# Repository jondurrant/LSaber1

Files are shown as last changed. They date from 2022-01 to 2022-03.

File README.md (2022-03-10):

# LSaber1
IOT Saber Wall Light based on Raspberry PI Pico, ESP-01S and WS2812 LEDs.

PIR and Switch activated wall light. Works as a group able to turn each other on and off via MQTT hub topics. 

# Hardware
+ Raspberry Pico
+ ESP-01S (1Mb) running ESP-AT 2.1
+ WS2812 144 LED strip
+ AM312 PIC
+ RGB CC LED
+ Resistors and Caps as in Schema
+ 5Amp 5Volt power supply
+ 5 Amp Fuse and 100C Thermal Fuse
+ M2 inserts for scew fixing of PCB to case and pommel onto case

## Schema 
A circuit diagram is available in KICAD format. Included in PCB folder.

Warning: The LEDs will draw 4Amps of current. You should assure yourself that the circuit and wiring can safely deliver that current. 

## ESP-01S
I got very cheap pack of ESP-01S but they came with 1Mb flash. Latest version of ESP-AT, version 2.2, requires 2MB. 

Fortunatly Jandrassy has built a working 2.1 firmware for 1MB. This is on github at: https://github.com/jandrassy/WiFiEspAT

To reliably upload the firmware to ESP-01S requires the RST IO0 to get pulled to zero and the released. Some further inform on how to do this at: https://blog.tiga.tech/flashing-esphome-firmware-to-esp-01s/

I used the RPI 4 to upload the firmware and the esptool.py. I had to drop frequency to 40m and change upload mode to dout in the download.config file. Then use the command
esptool.py --port /dev/ttyS0 write_flash @download.config

## Case
Case is 3D printed in PLA. I've modelled the case and wall mounts for the case in OpenSCAD. The model and SLA files available in the 3dmodels folder.

## Blade
Blade is a 20mm x 3mm x 1000mm OPAL Acrylic Tube. You can find these on ebay, though I found ebay quite expensive. Bought mine from [The Clear Plastic Shop](https://clearplastictube.co.uk/opal-acrylic-tube) in the UK. 

# Software

## C++ - For Raspberry PICO
+ [lwesp](https://github.com/MaJerle/lwesp): library for talking to ESP-AT over serial
+ + [forkedlwesp](https://github.com/jondurrant/lwespFork) Forked to allow MQTT over SSL. 
+ [FreeRTOS-Kernel](https://github.com/FreeRTOS/FreeRTOS-Kernel): dependency for lwesp
+ [json-maker](https://github.com/rafagafe/json-maker)
+ [tiny-json](https://github.com/rafagafe/tiny-json)
+ [RtosComponents](https://github.com/jondurrant/RtosComponents) - my library for watchdog and RGB PWM control
+ [twinThingPicoESP](https://github.com/jondurrant/twinThingPicoESP) - IOT Library
+ [PicoLED](https://github.com/ForsakenNGS/PicoLED) - Manage the WS2812 LEDs

## Python -  Management Software
+ [TwinThingPyMQTT](https://github.com/jondurrant/TwinThingPyMQTT) - Python version of IOT Library, including TwinMgr which is how the management software talks to all the devices.
+ Python3
+ dotmap
+ numpy
+ paho-mqtt
+ pandas
+ PyMySQL
+ pyOpenSSL
+ SQLAlchemy
+ [twinThing](https://github.com/jondurrant/twinThing) 
+ mysql Db
+ [emqx](https://www.emqx.io/) using Mysql authentication 
+ [Joern Weissenborn LCARS](http://joernweissenborn.github.io/lcars/) - LCARS Look and feel

## Python Test Code
Some test code to interact with the api are included in py/test folder. They expect some environment variables to point to the MQTT hub and credentials.
+ MQTT_USER - Username and Client Id to connect to MQTT
+ MQTT_PASSWD - Password to authenticate against MQTT
+ MQTT_HOST - Hostname of MQTT server
+ MQTT_PORT - Port that MQTT is listen on, normally 1883

# Build and Deploy

##Clone project
'''
git clone --recurse-submodules https://github.com/jondurrant/LSaber1
'''
main.cpp include "Credentials.env" for the Wifi AP name and passwd, MQTT Host, Port, Username and password. I've not included this file in the repo. Please create one looking something like this:

``` C++
#define SID "SID"
#define PASSWD "PWD"

#define MQTTHOST "IP"
#define MQTTPORT 1883
#define MQTTUSER "jon"
#define MQTTPASSWD "PWD"
```

## To build C++:
``` bash
mkdir build
cd build
cmake ..
make
make install (only work if you used my config setup in the Pico Intro course as does SWD upload of code direct from make).
```

For more on how I use a Raspberry PI to build, deploy code  and debug the Pico see my course on [Udemy](https://www.udemy.com/course/introduction-to-c-development-environment-for-raspberry-pico/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)

## Python Management Deployment
I have included a Docker file to build an image for the management software. It manipulates the Python path to include the right libraries, along with loading some from requirements.txt.

## EMQX
Setup EMQX using mysql authentication and acl. The [TwinThingPyMQTT](https://github.com/jondurrant/TwinThingPyMQTT) repo include the DDL to create the required tables.

Lights authenticate using the MAC address of the device for Client Id, Username and Password. They will require permissions within EMQX to access:
```
[
	{
	  "topic": "GRP/ALL/TPC/#",
	  "action": "sub",
	  "access": "allow"
	},
	{
	  "topic": "TNG/$CLIENTID/#",
	  "action": "pubsub",
	  "access": "allow"
	},
	{
	  "topic": "GRP/saber/TPC/#",
	  "action": "pubsub",
	  "access": "allow"
	}
]
```
The Management software will need access to:
```
[
	{
	  "topic": "GRP/ALL/TPC/#",
	  "action": "sub",
	  "access": "allow"
	},
	{
	  "topic": "TNG/$CLIENTID/#",
	  "action": "pubsub",
	  "access": "allow"
	},
	{
	  "topic": "GRP/saber/TPC/#",
	  "action": "pubsub",
	  "access": "allow"
	},
	{
	  "topic": "GRP/saber/TWIN/RES",
	  "action": "sub",
	  "access": "allow"
	},
	{
	  "topic": "GRP/saber/TWIN/GET",
	  "action": "pub",
	  "access": "allow"
	},
	{
	  "topic": "GRP/saber/TWIN/SET",
	  "action": "pub",
	  "access": "allow"
	}
]
```

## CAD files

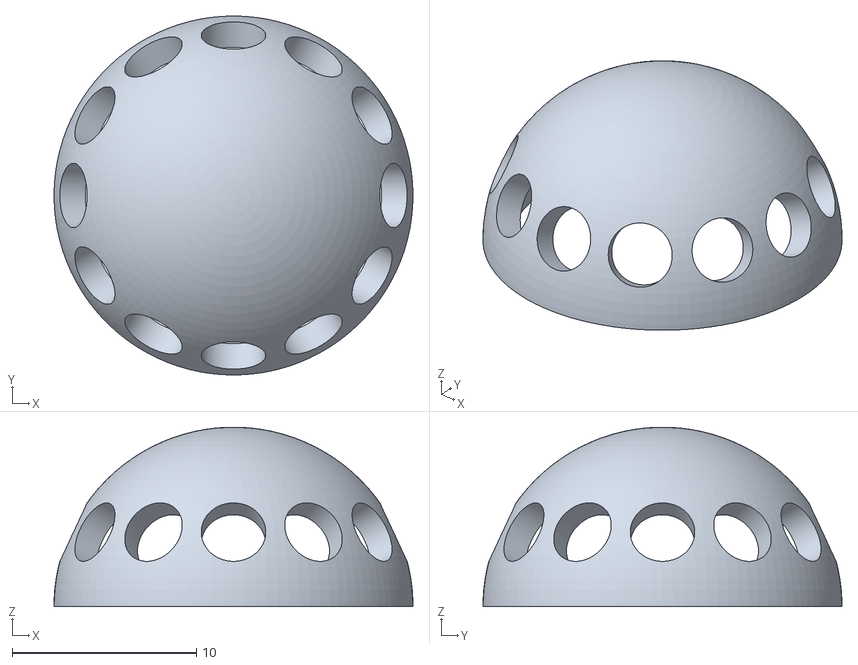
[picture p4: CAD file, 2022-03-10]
3dmodels/stl/cap.stl
19.5 x 19.5 x 9.75

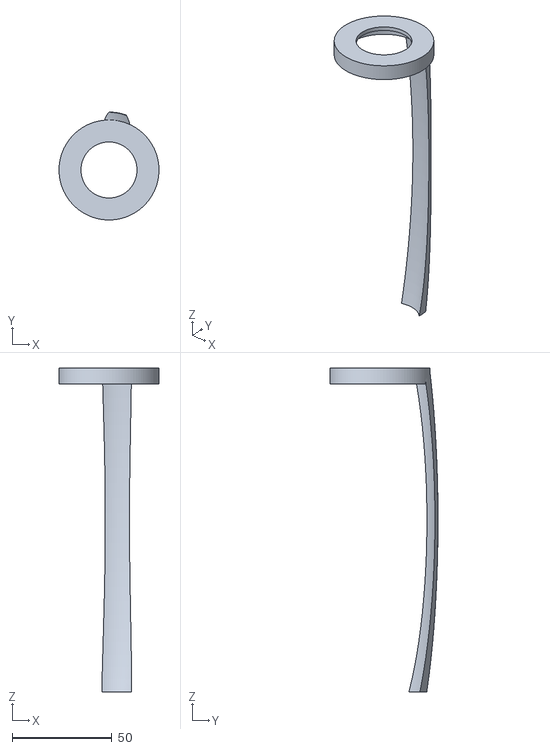
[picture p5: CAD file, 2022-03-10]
3dmodels/stl/guard.stl
50.0 x 54.0 x 162.0

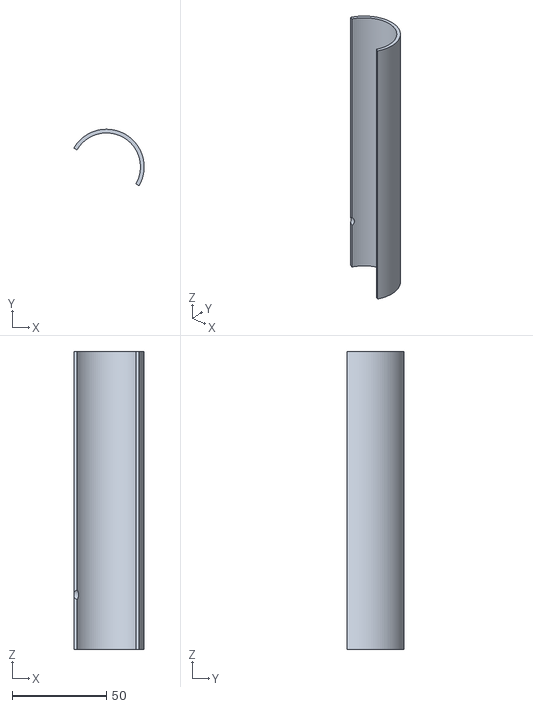
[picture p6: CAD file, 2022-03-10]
3dmodels/stl/gripRear.stl
37.3 x 30.0 x 158.0

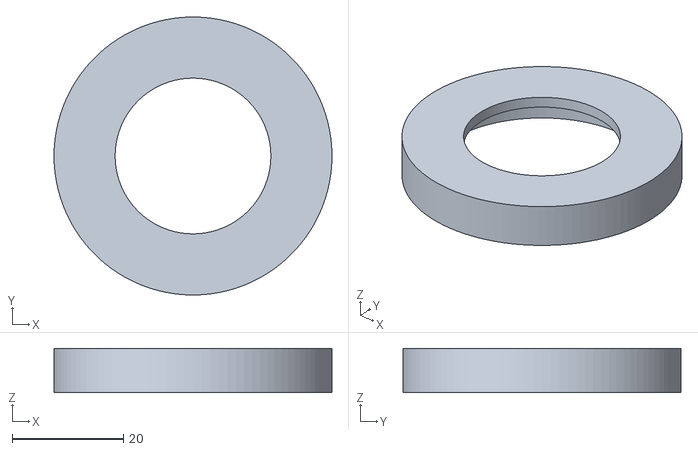
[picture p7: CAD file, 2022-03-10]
3dmodels/stl/guardShort.stl
50.0 x 50.0 x 8.00

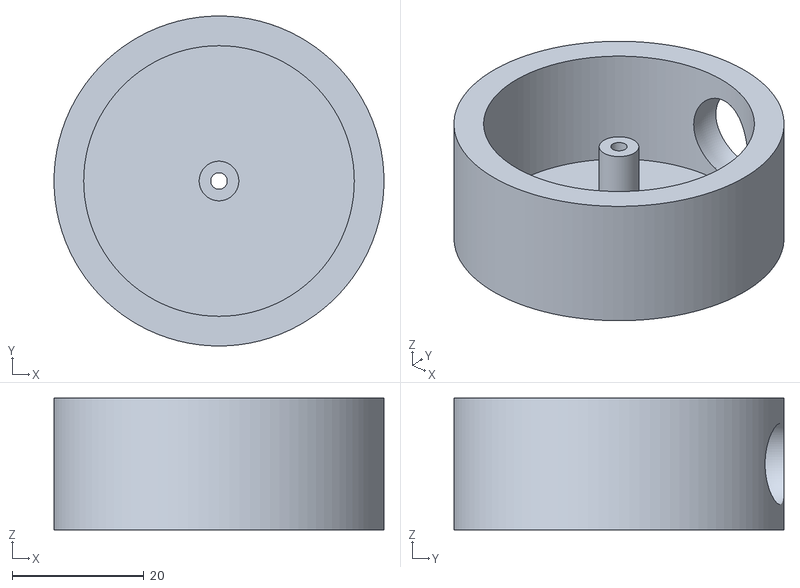
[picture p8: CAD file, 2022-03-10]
3dmodels/stl/pummel.stl
50.0 x 50.0 x 20.0

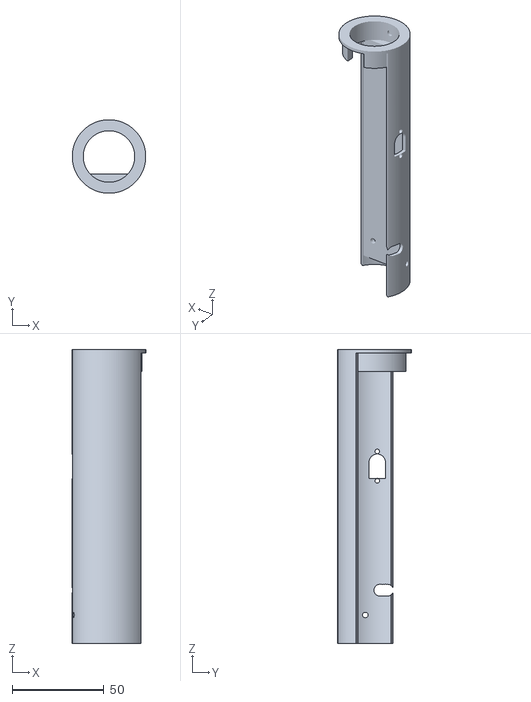
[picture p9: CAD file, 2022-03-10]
3dmodels/stl/gripBack.stl
40.0 x 40.0 x 160.0

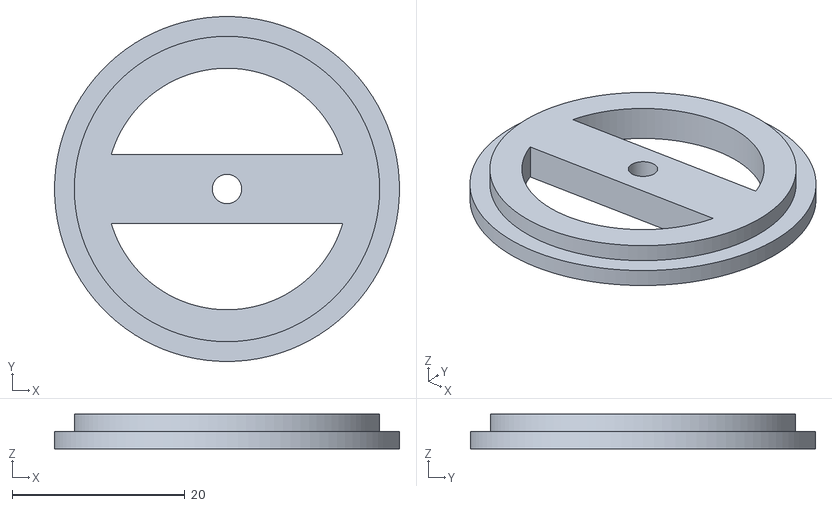
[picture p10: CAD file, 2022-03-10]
3dmodels/stl/pummelInt.stl
40.0 x 40.0 x 4.00

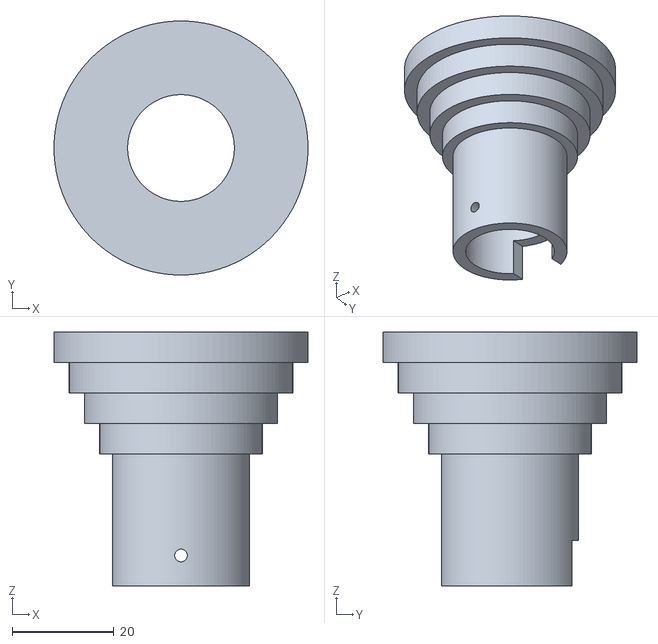
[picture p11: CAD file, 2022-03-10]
3dmodels/stl/stem.stl
50.0 x 50.0 x 50.0

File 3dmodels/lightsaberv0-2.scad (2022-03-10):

//Fixings
M5=5.5;
M4=4.5;
M3=3.5;
M2=2.5;
M3INSERT=3.7;
M2INSERT=3.4;


//Blade
BladeDiam=23;//24;
BladeDiamTrue=19.5;
BladeLen=100; //Debug only
BladeThick=3;

CapCollar=2;

//Pico
PicoWid=21;
PicoLen=64;
PicoDep=19;

//PIZ
PIZWid=34;
PIZLen=72;
PIZDep=19;
PCBGrid=2.54;

//Stem
StemLen=50;
StemCollar=0;//5;
StemSegLen=6;
StemSegMaxDiam=50;
StemSegStep=6;

//Grip
GripLen=160; //Max print size is 170
GripDiam=40;//45;
GripOverlap=12;

//Pummel
PummelDiam=GripDiam+10;
PummelIntDiam = GripDiam + 1;
PummelLen=20;
PummelOverlap=5;
PowerWid=11.5;
PowerLen=9;


//PCB
PCBWidth=30.5;
PCBLen=135;
PCBBRy=3.9;
PCBBRx=7.35;
PCBBLx=16.51;//15.51;
PCBBLy=9.4;
PCBTRx=0;
PCBTRy=90.79;
PCBLEDy=12.5;
PCBLEDx=10;
PCBLEDz=5;
PCBSwitchD=5 ;
PCBSwitchY=23.5;
PCBSwitchX=7.6;
PCBSwitchZ=15;//12;
PCBSwitchL=20;
PCBCapX=12;
PCBCapY=114;
PCBCapL=20;
PCBCapZ=PCBCapL/2;
PCBCapD=10.2;
PCBOffz=10;
PCBOffy=-10;



THICK=2;

$fn=100;


/*
Blade();
Pico();
PIZ();
*/
//Blade();
//PCB();
//PIR();

    
//BladeCap();

//Stem();
//GripBack();
//PummelInt();
//Pummel();
//translate([5,10,0]) GripFront();
//GripFront();

//Guard();
GuardShort();

//MountBottom();
//MountTop();



//Test print
/*
difference(){
    GripBack();
    translate([0,0,GripLen*(-0.85)])
        cube([PummelDiam, PummelDiam, GripLen], center=true);
}
*/




module Blade(){
    color("blue")
    translate([0,0,BladeLen/2]){
        difference(){
            cylinder(d=BladeDiam, h=BladeLen, center=true);
            cylinder(d=BladeDiam-(BladeThick*2), h=BladeLen+10, center=true);
        }
        
    }
}

module BladeCap(){
    inner = BladeDiamTrue-(BladeThick);
    translate([0,0,BladeLen]){
        //Half hollow Sphere
        difference(){
            sphere(d=BladeDiamTrue, $fn=100);
            sphere(d=inner);
            translate([0,0,BladeDiamTrue/(-2)]){
                cube([BladeDiamTrue+10, BladeDiamTrue+10, BladeDiamTrue], center=true);
            }
            
            
           for (x=[0:30:360]){
               rotate([0,0,x]){
                   rotate([0,65,0])
                      cylinder(d=M3, h=BladeThick*10, center=true);
               }
           }
  
            
        }
        //Connection collar
        /*
        difference(){
            cylinder(d=inner, h=CapCollar*2, center=true);
            cylinder(d=inner-(THICK*2), h=CapCollar*4, center=true);
        }
        */
    }
}

module Stem(){
    //Inner Tube
    translate([0,0,StemLen/(-2)]){
        difference(){
            cylinder(d=BladeDiam+(THICK*2), h=StemLen, center=true);
            cylinder(d=BladeDiam-(THICK), h=StemLen+10, center=true);
            translate([0,0,(StemLen/2)-(StemCollar/2)]){
                cylinder(d=BladeDiam, h=StemCollar, center=true);
            }
            
            //Coupline
            CoupZ=StemLen/(-2) + (GripOverlap/2);
            translate([0, 0, CoupZ]){
                //Hole
                rotate([90,0,0]){
                    cylinder(d=M2, h=BladeDiam+(THICK*4), center=true);
                }
                //Loose top
                translate([0, (BladeDiam+(THICK*2))/2, THICK*(-1)]){
                    //cube([BladeDiam+(THICK*2), BladeDiam+(THICK*2), GripOverlap-THICK], center=true);
                    cube([BladeDiam/2, BladeDiam+(THICK*2), GripOverlap-THICK], center=true);
                }
            }
        }
    }
    //Steps
    difference(){
        translate([0,0,StemSegLen/2]){
            for(i=[0:4]){
                translate([0, 0, (StemSegLen*(i+1))/(-1)]){
                    cylinder(d=StemSegMaxDiam-(StemSegStep*i), h=StemSegLen, center=true);
                }
            }
        }
        //Hole
        translate([0,0,StemLen/(-2)]){
            cylinder(d=BladeDiam, h=StemLen+10, center=true);
        }   
    }
}

function picoZ()=(StemLen + ((PicoLen+(THICK*4)) / (2)))* (-1) ;

module Pico(){
    z=picoZ();
    translate([0,0,z]){
        color("lightgrey"){
            cube([PicoWid, PicoDep, PicoLen], center=true);
        }
    }
}

module PIZ(){
    z=picoZ() - PIZLen ;
    translate([0,0,z]){
        color("lightGreen"){
            cube([PIZWid, PIZDep, PIZLen], center=true);
        }
    }
}


module GripBack(){
    difference(){
        GripTube();
        rotate([0,0,-30]){
            translate([0,GripDiam/2, gripTubeZ()-THICK]){
                cube([GripDiam+10,GripDiam,GripLen ], center=true);
            }
        }
    }
    stemCoupling();
}

module GripFront(){
    intersection(){
        difference(){
            GripTube();
            translate([0,0,gripTubeZ()]){
                cylinder(d=GripDiam - (THICK*2), h=GripLen+10, center=true);
            }
            rotate([0, 0, -30]){
                translate([0,GripDiam/(-2), gripTubeZ()]){
                    cube([GripDiam+10,GripDiam,GripLen+10 ], center=true);
                }
            }
            
            /*
            //Switch hole
            translate([0,PCBOffy,gripTubeZ()]){
                for(i=[-2:1:2]){
                    translate([PCBWidth/-2, PCBSwitchZ + i, PCBLen/-2-5.5+PCBSwitchY]){
                        rotate([0,90,0]){
                            cylinder(d=PCBSwitchD+1,h=20,center=true);
                        }
                    }
                }
            }
            */
        }
        
        rotate([0, 0, -30]){
            translate([0,GripDiam/2, gripTubeZ()-THICK]){
                cube([GripDiam+10,GripDiam,GripLen ], center=true);
            }
        }
    }
}
    
function gripTubeZ() = (StemLen + GripLen/2 - GripOverlap) *( -1);
module GripTube(){
    z=gripTubeZ();
    translate([0,0,z]){
        difference(){
            cylinder(d=GripDiam, h=GripLen, center=true);
            translate([0,0,THICK*(-1)]){
                cylinder(d=GripDiam - (THICK*2), h=GripLen, center=true);
            }
            //Stem Hole
            cylinder(d=BladeDiam+(THICK*2.5), h=GripLen+10, center=true);
            
            //LED hole
            translate([PCBWidth/-2, PCBLEDz*(-1), PCBLen/-2-9.5+PCBLEDy]){
                rotate([0,90,0]){
                    cylinder(d=3,h=20,center=true);
                }
            }
            
            //Switch hole
            translate([PCBWidth/-2, PCBSwitchZ+PCBOffy, PCBLen/-2-7+PCBSwitchY]){
                for(i=[-2:1:2]){
                    translate([0, i, 0]){
                        rotate([0,90,0]){
                            cylinder(d=PCBSwitchD+1.5,h=20,center=true);
                        }
                    }
                }
            }
            
            //PowerHole
            translate([PCBWidth/-2, -4.5, PCBLen/2-5]){
                translate([-5, 0, PowerSocketY*(-1)]){
                    rotate([90,0,0])
                        PowerSocketHole();
                }
            }
        }
    }
    
    stemCoupling();
    
    
    //PCB Mount
    translate([0,0,z-(GripOverlap/2)]){
        difference(){
            //PCB plate
            cylinder(d=GripDiam, h=GripLen-(GripOverlap), center=true);
            cube([GripDiam, PIZDep, GripLen], center=true);
            translate([0,GripDiam/2,0]){
                cube([GripDiam+10, GripDiam, GripLen+10], center=true);
            }
            translate([0,0,PCBLen/(-2)-5]){
                cube([GripDiam, GripDiam, 10], center=true);
            }
            
            //Mounting Holes
            translate([PCBWidth/-2,0, PCBLen/-2-1.5]){
                translate([PCBBRx,0,PCBBRy]){
                    rotate([90,0,0]){
                        cylinder(d=M2INSERT, h=BladeDiam+(THICK*4), center=true);
                    }
                    translate([PCBBLx,0, PCBBLy]){
                        rotate([90,0,0]){
                            cylinder(d=M2INSERT, h=BladeDiam+(THICK*4), center=true);
                        }
                    }
                    translate([PCBTRx,0, PCBTRy]){
                       rotate([90,0,0]){
                            cylinder(d=M2INSERT, h=BladeDiam+(THICK*4), center=true);
                        }
                    }
                }
            }
            
            
            /*
            //PCB Weight Holes
            pcbCountX=GripDiam/PCBGrid/2-2;
            pcbCountY=(GripLen-GripOverlap)/PCBGrid/2;
            for (y=[0:5:pcbCountY]){
                for (j=[-1,1]){
                    translate([0, 0, y*j*PCBGrid]){
                        for (x=[0:3:pcbCountX]){
                            for (i=[-1,1]){
                                translate([x*i*PCBGrid,0,0]){
                                    rotate([90,0,0]){
                                        cylinder(d=M2INSERT, h=BladeDiam+(THICK*4), center=true);
                                    }
                                }
                            }
                        }
                    }
                }
            }
            */
            
        }
    }
}
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

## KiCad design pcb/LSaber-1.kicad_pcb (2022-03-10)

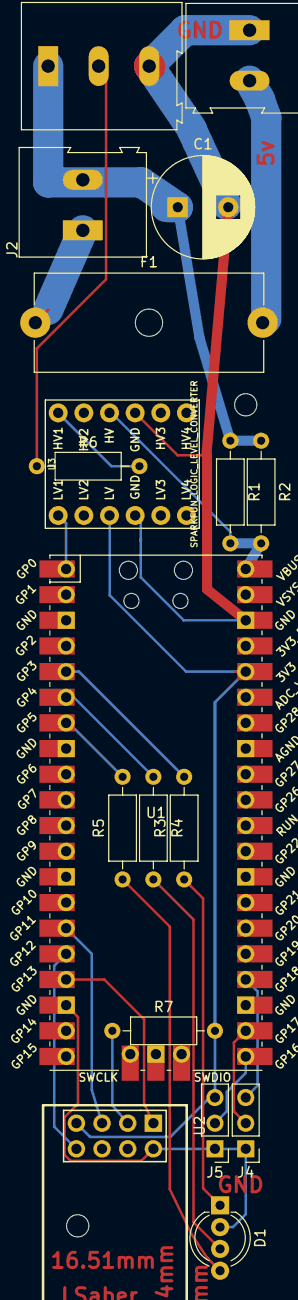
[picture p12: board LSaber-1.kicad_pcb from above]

Board: 2 copper layers, 18 parts (0 on the bottom side), 22 nets.

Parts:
C1: CP; CP_Radial_D10.0mm_P5.00mm
D1: LED_RCGB; LED_D5.0mm-4_RGB_Wide_Pins
F1: Fuse 5A; Fuseholder_Cylinder-5x20mm_Schurter_0031_8201_Horizontal_Op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
J1, J2: Screw_Terminal_01x02; TerminalBlock_Altech_AK300-2_P5.00mm
J3: Screw_Terminal_01x03; TerminalBlock_Altech_AK300-3_P5.00mm
J4, J5: Conn_01x03_Male; PinHeader_1x03_P2.54mm_Vertical
R1, R2: 10R; R_Axial_DIN0207_L6.3mm_D2.5mm_P10.16mm_Horizontal
R3, R4, R5: 92R; R_Axial_DIN0207_L6.3mm_D2.5mm_P10.16mm_Horizontal
R6: 330R; R_Axial_DIN0207_L6.3mm_D2.5mm_P10.16mm_Horizontal
R7: 10K; R_Axial_DIN0207_L6.3mm_D2.5mm_P10.16mm_Horizontal
U1: Pico; RPi_Pico_SMD_TH
U2: ESP-01v090; ESP-01
U3: SPARKFUN_LOGIC_LEVEL_CONVERTER

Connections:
+3V3: J5.3, R7.2, U1.36, U2.7, U3.LV
+5V: F1.2, J1.2
GND: C1.2, D1.2, J1.1, J3.3, J4.1, J5.1, U1.18, U1.38, U2.2, U3.GND1, U3.GND2
unnamed: C1.1, J2.2, J3.1, R1.1, R2.1
unnamed: D1.1, R3.1
unnamed: D1.3, R4.2
unnamed: D1.4, R5.1
unnamed: J3.2, R6.1
unnamed: F1.1, J2.1
unnamed: J4.2, U1.22
unnamed: J4.3, U1.24
unnamed: J5.2, U1.21
unnamed: R1.2, R2.2, U1.40, U3.HV
unnamed: R3.2, U1.5
unnamed: R4.1, U1.6
unnamed: R5.2, U1.7
unnamed: R6.2, U3.HV1
unnamed: R7.1, U2.3
unnamed: U1.1, U3.LV1
unnamed: U1.15, U2.5
unnamed: U1.16, U2.8
unnamed: U1.17, U2.1

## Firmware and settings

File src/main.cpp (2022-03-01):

#include <stdio.h>
#include "pico/stdlib.h"
#include "FreeRTOS.h"
#include "task.h"
#include <array>
#include "lwesp/lwesp.h"
#include <stdint.h>

#include "lwesp/apps/lwesp_mqtt_client_api.h"

#include <WatchdogBlinkAgent.h>

#include "pico/multicore.h"

#include <PicoLed.hpp>




//Local include file not in git repository, defining the credentials
#include "Credentials.env"
#ifndef SID
#define SID "sid"
#define PASSWD "passwd"
#endif
#ifndef MQTTHOST
#define MQTTHOST "MQTTSERVER"
#define MQTTPORT 1883
#define MQTTUSER "USER"
#define MQTTPASSWD "PASSWD"
#endif


#include "MQTTAgent.h"
#include "MQTTRouterPing.h"
#include "MQTTRouterTwin.h"

#include <WifiHelper.h>

#include "StateExample.h"
#include "ExampleAgentObserver.h"
#include "RGBLEDMgr.h"
#include "RGBLEDAgent.h"
#include "SaberState.h"
#include "BladeMgr.h"
#include "BladeStateAgent.h"
#include "MQTTRouterSaber.h"


void core1_entry() {
	BladeMgr blade;
	blade.loopForever();

}

void runTimeStats( ){
	TaskStatus_t *pxTaskStatusArray;
	volatile UBaseType_t uxArraySize, x;
	unsigned long ulTotalRunTime, ulStatsAsPercentage;

   /* Take a snapshot of the number of tasks in case it changes while this
   function is executing. */
   uxArraySize = uxTaskGetNumberOfTasks();

   /* Allocate a TaskStatus_t structure for each task.  An array could be
   allocated statically at compile time. */
   pxTaskStatusArray = (TaskStatus_t *)pvPortMalloc( uxArraySize * sizeof( TaskStatus_t ) );

   if( pxTaskStatusArray != NULL ){
      /* Generate raw status information about each task. */
      uxArraySize = uxTaskGetSystemState( pxTaskStatusArray,
                                 uxArraySize,
                                 &ulTotalRunTime );

      /* For percentage calculations. */
      ulTotalRunTime /= 100UL;

	 /* For each populated position in the pxTaskStatusArray array,
	 format the raw data as human readable ASCII data. */
	 for( x = 0; x < uxArraySize; x++ )
	 {
		/* What percentage of the total run time has the task used?
		This will always be rounded down to the nearest integer.
		ulTotalRunTimeDiv100 has already been divided by 100. */
		if( ulTotalRunTime > 0 ) {
			ulStatsAsPercentage =
				  pxTaskStatusArray[ x ].ulRunTimeCounter / ulTotalRunTime;
		} else {
			ulStatsAsPercentage = 0;
		}

		if( ulStatsAsPercentage > 0UL )
		{
		   printf("%s tt:%l utt:%l u%%r\n",
							 pxTaskStatusArray[ x ].pcTaskName,
							 pxTaskStatusArray[ x ].ulRunTimeCounter,
							 ulStatsAsPercentage );
		}
		else
		{
		   /* If the percentage is zero here then the task has
		   consumed less than 1% of the total run time. */
		   printf("%s tt:%l utt<1%% bp:%d cp:%d state:%d\n",
							 pxTaskStatusArray[ x ].pcTaskName,
							 pxTaskStatusArray[ x ].ulRunTimeCounter,
							 pxTaskStatusArray[ x ].uxBasePriority,
							 pxTaskStatusArray[ x ].uxCurrentPriority,
							 pxTaskStatusArray[ x ].eCurrentState
							 );
		}
	 }

      /* The array is no longer needed, free the memory it consumes. */
      vPortFree( pxTaskStatusArray );
   }else {
 	  printf("Malloc failed\n");
   }
}




void
init_thread(void* pvParameters) {
	char mqttTarget[] = MQTTHOST;
	lwesp_port_t mqttPort = MQTTPORT;
	char mqttUser[] = MQTTUSER;
	char * pMqttUser = mqttUser;
	char mqttPwd[] = MQTTPASSWD;
	char * pMqttPwd = mqttPwd;
	char macs[15];
	bool ssl= false;


	WatchdogBlinkAgent watchdog;
	watchdog.start(tskIDLE_PRIORITY+1);

	MQTTRouterSaber mqttRouter;
	SaberState state;

	MQTTAgent mqttAgent(512, 512);
	BladeStateAgent xTwin;
	MQTTPingTask xPing;

	RGBLEDAgent xLed(3, 4, 5);
	xLed.start(tskIDLE_PRIORITY+1);
	xLed.set(RGBModeOn, 0xFF, 0xFF, 0xFF);
	RGBLEDMgr xLedMgr(&xLed);

	//Connect to WiFi
	if (WifiHelper::connectToAp(SID, PASSWD)){
		char ips[16];
		WifiHelper::getIPAddressStr(ips);
		printf("WIFI IP %s\n", ips);
		if (WifiHelper::getMACAddressStr(macs)){
			printf("MAC %s\n", macs);
			if (strcmp(mqttUser, "MAC") == 0){
				pMqttUser = macs;
			}
			if (strcmp(mqttPwd, "MAC") == 0){
				pMqttPwd = macs;
			}
		} else {
			printf("MAC NOT AVAILABLE\n");
		}
		WifiHelper::syncRTCwithSNTP();


		//Set up the credentials so we have an ID for our thing
		mqttAgent.credentials(pMqttUser, pMqttPwd);
		mqttRouter.init(mqttAgent.getId(), &mqttAgent);

		//Twin agent to manage the state
		xTwin.setStateObject(&state);
		xTwin.setMQTTInterface(&mqttAgent);
		xTwin.start(tskIDLE_PRIORITY+1);
		xTwin.setTopics(mqttRouter.getGroupTopicOn(), mqttRouter.getGroupTopicOff());

		//Start up a Ping agent to mange ping requests
		xPing.setInterface(&mqttAgent);
		xPing.start(tskIDLE_PRIORITY+1);

		//Give the router the twin and ping agents
		mqttRouter.setTwin(&xTwin);
		mqttRouter.setPingTask(&xPing);

		//Setup and start the mqttAgent
		mqttAgent.setObserver(&xLedMgr);
		mqttAgent.setRouter(&mqttRouter);

#ifdef MQTTSSL
		ssl = true;
#endif
		mqttAgent.connect(mqttTarget, mqttPort, true, ssl);

		mqttAgent.start(tskIDLE_PRIORITY+1);

	} else {
		xLed.set(RGBModeSlow, 0xFF, 0xff, 0xff);
	}

	//xLed.start(tskIDLE_PRIORITY);

    for (;;){
    	vTaskDelay(5000);

    	if (! WifiHelper::isJoined()){
    		while (! WifiHelper::connectToAp(SID, PASSWD)){
    			vTaskDelay(5000);
    		}
    		char ips[16];
			WifiHelper::getIPAddressStr(ips);
			printf("WIFI IP %s\n", ips);
    	}

    	//runTimeStats();
    }
}



int main() {

	stdio_init_all();

	sleep_ms(3000);
	printf("******GO******\n");

	multicore_reset_core1 ();
	multicore_launch_core1(core1_entry);


    BaseType_t atReturned;
	TaskHandle_t atHandle = NULL;

	atReturned = xTaskCreate(
					init_thread,
					"Init task",
					512,
					( void * ) 1,
					tskIDLE_PRIORITY+1,
					&atHandle );




    vTaskStartScheduler();
    while(1)
    {
        configASSERT(0);    /* We should never get here */
    }

}

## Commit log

2021-12-04 PIR and Switch working
2022-01-21 Needs comments and debug removed. Issue with nrgb not being set
    [main.cpp]
2022-01-24 Added comments and switched to support TLS
2022-03-10 Working code with DEBUG turned on.
    [LSaber-1.kicad_pcb, LSaber-1.sch, cap.stl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]
